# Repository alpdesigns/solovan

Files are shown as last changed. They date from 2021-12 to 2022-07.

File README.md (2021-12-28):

# Solovan
Solovan is a 15x3 ortholinear mechanical keyboard.

## Build Guides / ビルドガイド

- [Rev.A](./buildguide/rev_a)

## Firmware / ファームウェア

This keyboard uses the QMK firmware.

- https://github.com/alpdesigns/qmk_firmware
## PCB Data / 基板データ
### PCB Data License
- Licensed under a [Creative Commons Attribution-NonCommercial-ShareAlike 4.0 International License](http://creativecommons.org/licenses/by-nc-sa/4.0/) (CC BY-NC-SA 4.0) otherwise noted. 
- For footprints see https://github.com/kymok/kicad-libs.

### data

- [Rev.A](./pcb/rev_a) (MCU: ATMEGA32u4)

## Bottom Plate Data / 底面プレートデータ

### Bottom Plate Data License

(C) ALP Designs 2021 All Rights Reserved.
- The data are provided for convenience of making accessories such as jigs or fixtures.
- 治具や固定金物などのアクセサリ制作に便利なよう，穴位置の図面を公開しています．

### data

- [Rev.A](./drawings/)

## Discord

- https://discord.gg/nhzya4kw

## Acknowledgements / 謝辞

I am grateful to [しろし](https://twitter.com/shirofox) for discussing the spec and giving me useful feedbacks through prototyping phase. Also [オタヒーのサメ](https://twitter.com/otahinosame) for naming this keyboard. [QMK Firmware](https://qmk.fm), [KiCad](https://www.kicad.org), [REMAP](https://remap-keys.app) were the indispensable OSS projects that this keyboard relies on. I would like to thank [SMKiJ members](https://self-made-keyboards-in-japan.github.io) for generously sharing their experience and knowledge.

開発にあたり，[しろし](https://twiter.com/shirofox)さんに仕様の議論とプロトタイプの試用にご協力いただきました．[オタヒーのサメ](https://twitter.com/otahinosame)さんにはキーボードを命名していただきました．また，[QMK Firmware](https://qmk.fm), [KiCad](https://www.kicad.org), [REMAP](https://remap-keys.app) は欠くことのできない重要な OSS プロジェクトでした．経験と知識を日々共有してくださる [SMKiJ](https://self-made-keyboards-in-japan.github.io) の皆様には日々お世話になっています．この場を借りて感謝申し上げます．

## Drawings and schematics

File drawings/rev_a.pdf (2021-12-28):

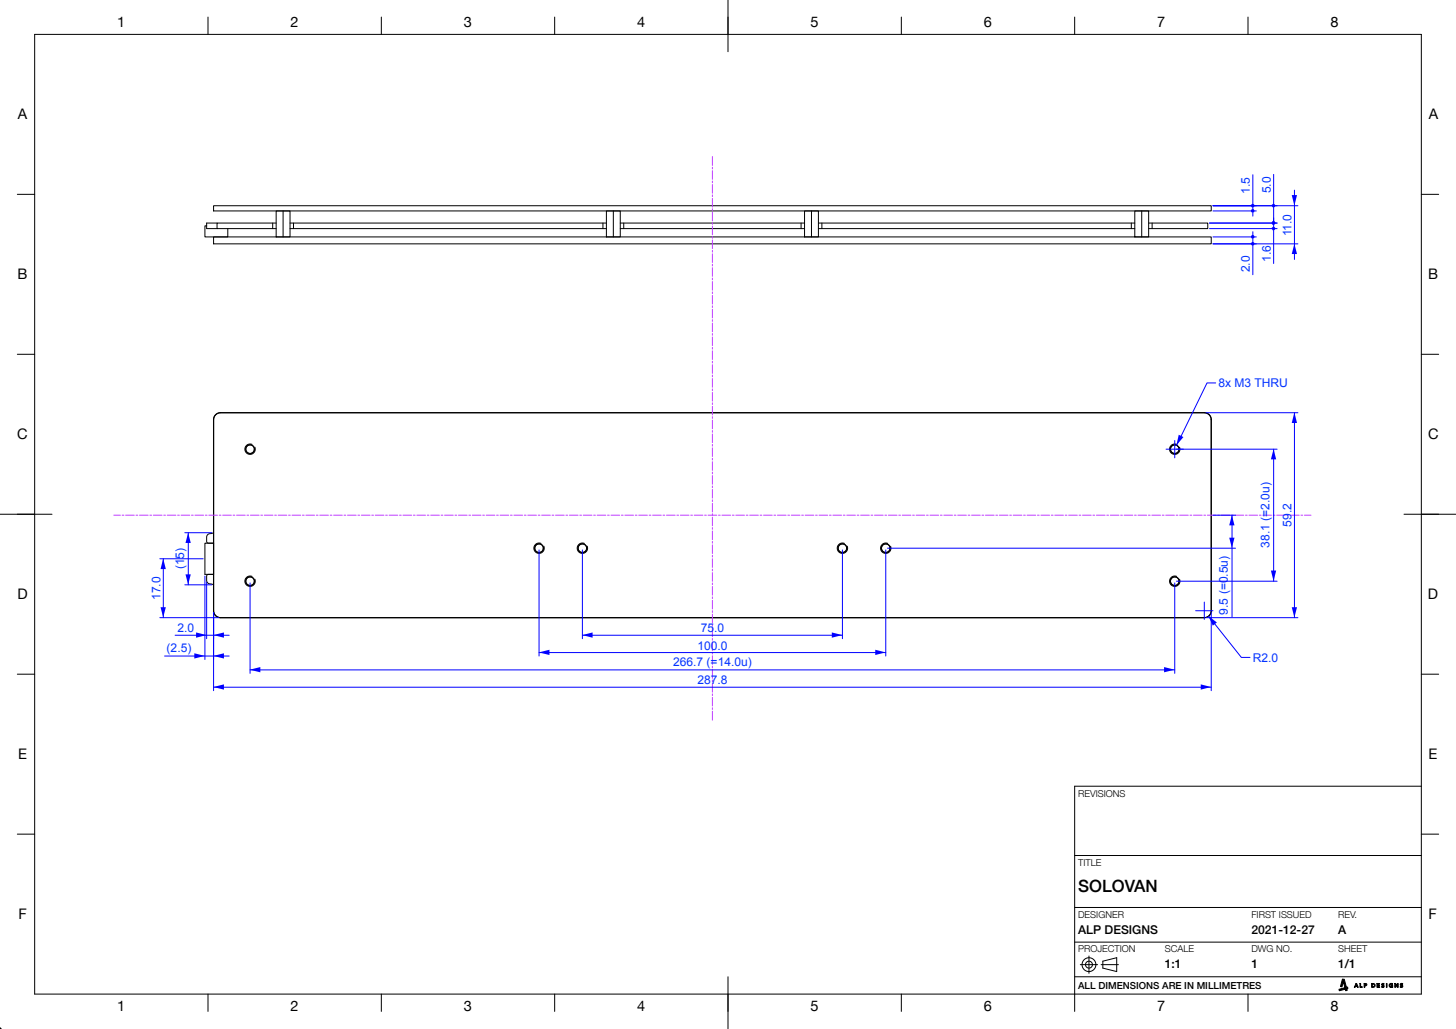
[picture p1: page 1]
8x M3 THRU; ALP DESIGNS; FIRST ISSUED; DWG NO.

ALL DIMENSIONS ARE IN MILLIMETRES

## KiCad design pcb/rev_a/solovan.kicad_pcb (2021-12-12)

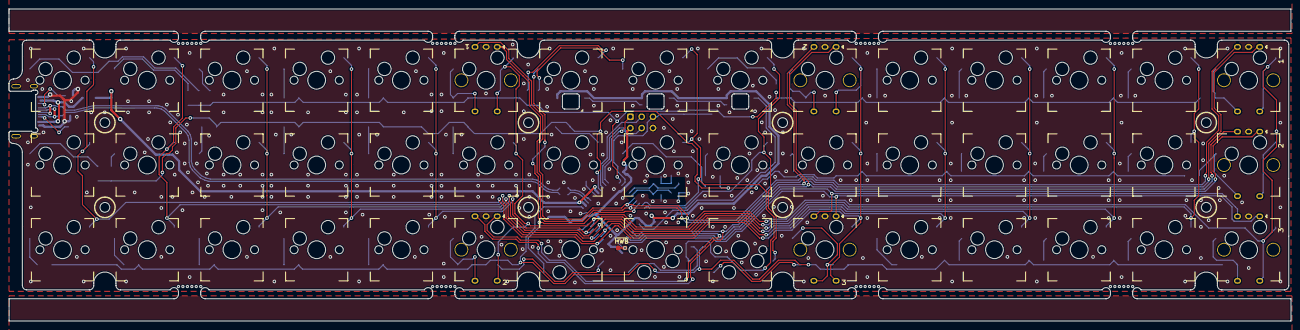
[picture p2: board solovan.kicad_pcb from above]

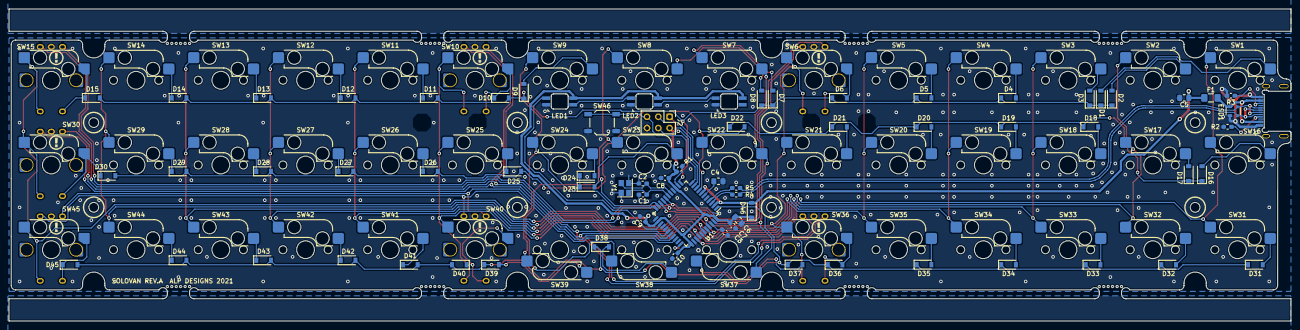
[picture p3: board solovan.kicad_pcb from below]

Board: 2 copper layers, 288.3 x 70.1 mm, 133 parts (71 on the bottom side), 85 nets.

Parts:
C1: 10p; C_0603_1608Metric_Pad1.08x0.95mm_HandSolder
C2: 10p; C_0603_1608Metric_Pad1.05x0.95mm_HandSolder
C3, C7, C8, C9, C10: 0.1u; C_0603_1608Metric_Pad1.05x0.95mm_HandSolder
C4, C5, C6: 1u; C_0805_2012Metric_Pad1.15x1.40mm_HandSolder
D1, D2, D3, D4, D5, D6, D7, D8, D9, D10, D11, D12, D13, D14, D15, D16, D17, D18, D19, D20, D21, D22, D23, D24, D25, D26, D27, D28, D29, D30, D31, D32, D33, D34, D35, D36, D37, D38, D39, D40, D41, D42, D43, D44, D45: 1N4148W; D_SOD-123
D46: 1N5819HW-7-F; D_SOD-123
ESD1: PRTR5V0U2X; SOT-143B
F1: 1206L050YR; Fuse_1206_3216Metric_Pad1.42x1.75mm_HandSolder
H1, H2, H3, H4, H5, H6, H7, H8: MountingHole; MountingHole_M2
H11, H12, H13, H14, H15, H16, H17, H18: MountingHole; Breakaway
J1: USB_C_Receptacle_USB2.0; HRO_TYPE_C_31_M_13
J2: ICSP; ICSP_ConnThrough
LED1, LED2, LED3: YS-SK6812MINI-E
NT1: Net-Tie_2; NetTie
R1: 10k; R_0603_1608Metric_Pad1.05x0.95mm_HandSolder
R2, R3: 5.1k; R_0603_1608Metric_Pad1.05x0.95mm_HandSolder
R4, R5: 22; R_0603_1608Metric_Pad1.05x0.95mm_HandSolder
SW1, SW2, SW3, SW4, SW5, SW7, SW8, SW9, SW11, SW12, SW13, SW14, SW16, SW17, SW18, SW19, SW20, SW21, SW22, SW23, SW24, SW25, SW26, SW27, SW28, SW29, SW31, SW32, SW33, SW34, SW35, SW37, SW38, SW39, SW41, SW42, SW43, SW44: Kailh MX Socket; SW_Cherry_MX_1.00u_Kailh
SW6, SW10, SW15, SW30, SW36, SW40, SW45: Rotary_Encoder_Switch_MP; SW_Cherry_MX_1.00u_Kailh_EC12
SW46: TS-1187A-B-A-B; SW_SPST_TL3342
U1: ATmega32U4-AU; TQFP-44_10x10mm_P0.8mm
Y1: X322516MLB4SI; Crystal_SMD_3225-4Pin_3.2x2.5mm

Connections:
/Col01: SW1.2, SW10.S1, SW16.2, SW25.2, SW31.2, SW40.S1, U1.36
/Col02: SW2.2, SW11.2, SW17.2, SW26.2, SW32.2, SW41.2, U1.37
/Col03: SW3.2, SW12.2, SW18.2, SW27.2, SW33.2, SW42.2, U1.38
/Col04: SW4.2, SW13.2, SW19.2, SW28.2, SW34.2, SW43.2, U1.39
/Col05: SW5.2, SW14.2, SW20.2, SW29.2, SW35.2, SW44.2, U1.40
/Col06: SW6.S1, SW15.S1, SW21.2, SW30.S1, SW36.S1, SW45.S1, U1.41
/Col07: SW7.1, SW22.1, SW37.2, U1.20
/Col08: SW8.2, SW23.2, SW38.1, U1.21
/Col09: SW9.2, SW24.2, SW39.1, U1.22
/D+: R5.1, U1.4
/D-: R4.1, U1.3
/MISO: J2.1, U1.11
/MOSI: J2.4, U1.10
/RE1A: SW6.A, SW15.A, U1.19
/RE1B: SW6.B, SW15.B, U1.18
/RE2A: SW10.A, SW30.A, SW36.A, U1.29
/RE2B: SW10.B, SW30.B, SW36.B, U1.28
/RE3A: SW40.A, SW45.A, U1.31
/RE3B: SW40.B, SW45.B, U1.30
/RGBLED: LED1.4, U1.25
/Row1: D1.1, D2.1, D3.1, D4.1, D5.1, D6.1, D7.1, D8.1, D9.1, D10.2, D11.2, D12.2, D13.2, D14.2, D15.2, U1.12
/Row2: D16.1, D17.1, D18.1, D19.1, D20.1, D21.1, D22.1, D23.1, D24.1, D25.2, D26.2, D27.2, D28.2, D29.2, D30.2, U1.8
/Row3: D31.1, D32.1, D33.1, D34.1, D35.1, D36.1, D37.1, D38.1, D39.1, D40.2, D41.2, D42.2, D43.2, D44.2, D45.2, U1.1
/SCK: J2.3, U1.9
/USBC_D1+: ESD1.3, J1.A6, J1.B6, R5.2
/USBC_D1-: ESD1.2, J1.A7, J1.B7, R4.2
/~RESET: J2.5, R1.2, SW46.1, U1.13
GND: C1.2, C2.2, C3.1, C4.1, C5.2, C6.2, C7.2, C8.2, C9.2, C10.2, ESD1.1, J1.A1, J1.A12, J1.B1, J1.B12, J1.S1, J2.6, LED1.3, LED2.3, LED3.3, NT1.2, R2.1, R3.1, SW6.C, SW10.C, SW15.C, SW30.C, SW36.C, SW40.C, SW45.C, SW46.2, U1.5, U1.15, U1.23, U1.35, U1.43, Y1.2, Y1.4
unnamed: C1.1, U1.17, Y1.1
unnamed: C2.1, U1.16, Y1.3
unnamed: C3.2, U1.42
unnamed: C4.2, U1.6
unnamed: D1.2, SW1.1
unnamed: D2.2, SW2.1
unnamed: D3.2, SW3.1
unnamed: D4.2, SW4.1
unnamed: D5.2, SW5.1
unnamed: D6.2, SW6.S2
unnamed: D7.2, SW7.2
unnamed: D8.2, SW8.1
unnamed: D9.2, SW9.1
unnamed: D10.1, SW10.S2
unnamed: D11.1, SW11.1
unnamed: D12.1, SW12.1
unnamed: D13.1, SW13.1
unnamed: D14.1, SW14.1
unnamed: D15.1, SW15.S2
unnamed: D16.2, SW16.1
unnamed: D17.2, SW17.1
unnamed: D18.2, SW18.1
unnamed: D19.2, SW19.1
unnamed: D20.2, SW20.1
unnamed: D21.2, SW21.1
unnamed: D22.2, SW22.2
unnamed: D23.2, SW23.1
unnamed: D24.2, SW24.1
unnamed: D25.1, SW25.1
unnamed: D26.1, SW26.1
unnamed: D27.1, SW27.1
unnamed: D28.1, SW28.1
unnamed: D29.1, SW29.1
unnamed: D30.1, SW30.S2
unnamed: D31.2, SW31.1
unnamed: D32.2, SW32.1
unnamed: D33.2, SW33.1
unnamed: D34.2, SW34.1
unnamed: D35.2, SW35.1
unnamed: D36.2, SW36.S2
unnamed: D37.2, SW37.1
unnamed: D38.2, SW38.2
unnamed: D39.2, SW39.2
unnamed: D40.1, SW40.S2
unnamed: D41.1, SW41.1
unnamed: D42.1, SW42.1
unnamed: D43.1, SW43.1
unnamed: D44.1, SW44.1
unnamed: D45.1, SW45.S2
unnamed: J1.A5, R2.2
unnamed: J1.B5, R3.2
unnamed: LED1.2, LED2.4
unnamed: LED2.2, LED3.4
unnamed: NT1.1, U1.33
UVCC-L: C5.1, D46.2, F1.1, U1.2, U1.7
VBUS-L: ESD1.4, F1.2, J1.A4, J1.A9, J1.B4, J1.B9
VCC-L: C6.1, C7.1, C8.1, C9.1, C10.1, D46.1, J2.2, LED1.1, LED2.1, LED3.1, R1.1, U1.14, U1.24, U1.34, U1.44

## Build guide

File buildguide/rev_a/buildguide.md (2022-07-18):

# Solovan Build Guide (Rev.A)

- `2022-01-05` Added instruction for back plate orientation

This build guide is translated from Japanese version. If there is any conflict, Japanese version should prevail.

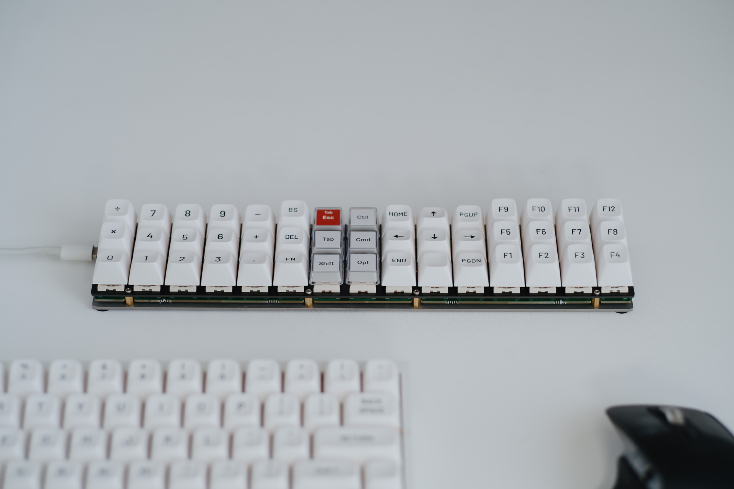
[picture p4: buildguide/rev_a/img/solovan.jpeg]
Solovan


Thank you for purchasing Solovan! 

Solovan is a 3x15 ortholinear keyboard. The board can be used as a depth saver or a adding some 40% to 60% keyboard. Also, it features 75 and 100 mm pitch M3 screw holes on the back side which is useful for attaching it to a display or a LCD tablet using commercially available hardwares (not included). Blasted stainless steel and dark grey anodised aluminum plate contributes its classy look and feel.

## Precautions

- This kit is for keyboard enthusiasts with proper knowledge of DIY keyboard.
- Some parts are fragile or may have sharp corners. Please handle with care.
- Sorry, but firmware development is not supported.

Products are carefully checked before shipment but please double-check for initial defects. If any problem, contact the seller within one week of receipt.

1. Check all parts are included in the box.
2. Check with [Remap](https://remap-keys.app) that all keys are working.

### About LEDs

Solovan has three LEDs which illuminates white when layer 1, 2 and 3 is active respectively. Modification to the firmware is required to change this behaviour. See [README](../../README.md) for the link to the firmware source code.

(LED flashes red when connected to USB.)

## Required Parts Not Included in the Kit

### Parts

|Item|Qty|
|:--|:--|
|Cherry MX key switch (or equivalent)|45|
|Cherry MX keycap 1u|45|
|Rotary encoder|3 max|
|Knob for rotary encoder|3 max|

Following rotary encoders can be used.

- ALPS EC12E2420801
- BOURNS PEC12R-4222F-S0024

### Equipments

|Item|Qty|
|:--|:--|
|USB Type-C data cable|1|
|Computer with Google Chrome (WebUSB must be enabled)|1|
|Tools|1 set|

Note: WebUSB may have been disabled in Google Chrome managed by your organization.

Following tools are recommended.

- Soldering iron and its holder
- Tweezers
- Side cutters
- Long-nose pliers or a M2 nut driver
- Screwdriver (+0)
- Solder and flux
- Solder wick
- Circuit tester with continuity check buzzer

## Inspection

### Parts in the Box

Following parts are included in this kit. Please check the quantity immediately after opening it.

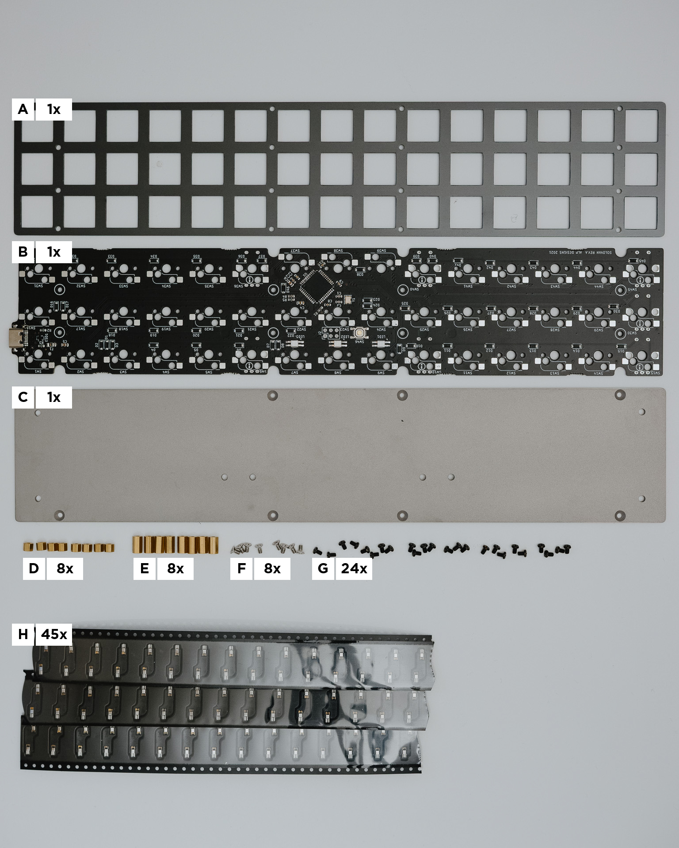
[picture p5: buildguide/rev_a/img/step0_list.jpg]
List of parts


|Symbol|Name|Qty|Rmks|
|:--|:--|:--|:--|
|A|Switch Plate|1||
|B|PCB|1||
|C|Bottom Plate|1||
|D|Standoff (M2x3.5 mm)|8|[Hirosugi ASB-2003.5CE](https://hirosugi.co.jp/products/B/ASB-CE.html) or equiv.|
|E|Standoff (M2x7.5 mm)|8|[Hirosugi ASB-2007.5CE](https://hirosugi.co.jp/products/B/ASB-CE.html) or equiv.|
|F|M2x4 stainless steel countersink screw|8|[Wilco UF-0204](https://wilco.jp/products/U/UF.html#page1) or equiv.|
|G|M2x3 black steel screw|24|[Wilco F-0230EB-03](https://wilco.jp/products/F/F-EB-03.html) or equiv.|
|H|Kailh MX socket|45||

### Inspecting the PCB

#### Inspecting Key Matrix

1. Access https://remap-keys.app with Google Chrome.
2. Connect Solovan.
3. Switch to key matrix testing mode.
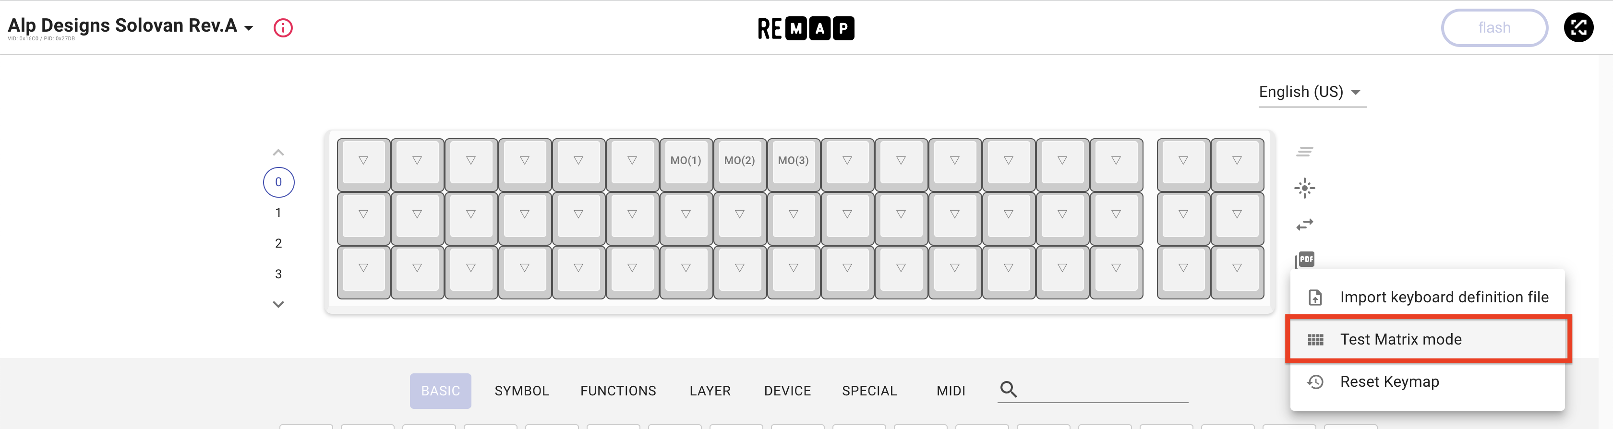
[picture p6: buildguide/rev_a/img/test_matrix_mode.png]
Testing mode
    - 
4. Short the pair of pads for each switches.
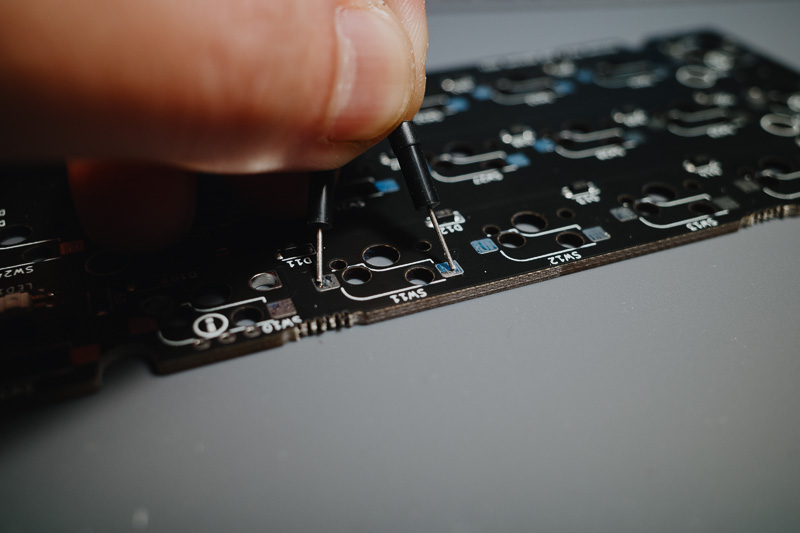
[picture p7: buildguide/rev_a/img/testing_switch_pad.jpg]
Shorting pads
    - 
5. Success if all switch except right cluster is highlighted. (The right cluster is for rotary encoders)
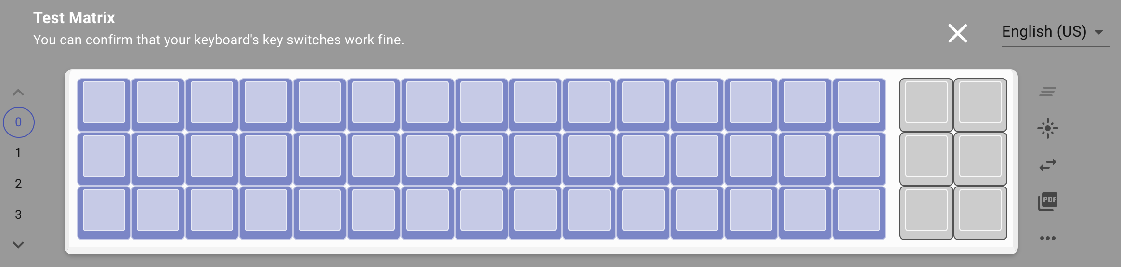
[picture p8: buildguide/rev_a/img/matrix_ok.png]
Success
    - 

#### Inspecting Rotary Encoder Circuit

1. Assign `MO(1)`, `MO(2)` for rotary encoder keys.
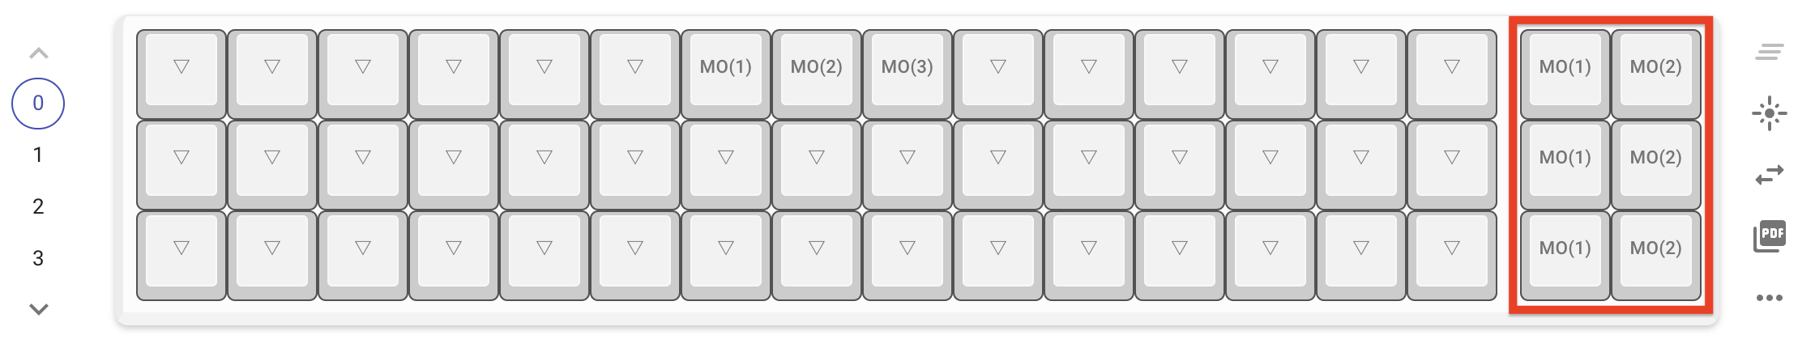
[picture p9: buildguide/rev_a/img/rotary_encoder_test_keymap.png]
rotary encoder inspection keymap
    - 
2. Half insert the rotary encoder and try turning the shaft to the left and right. Make sure that three pins touch the hole wall.
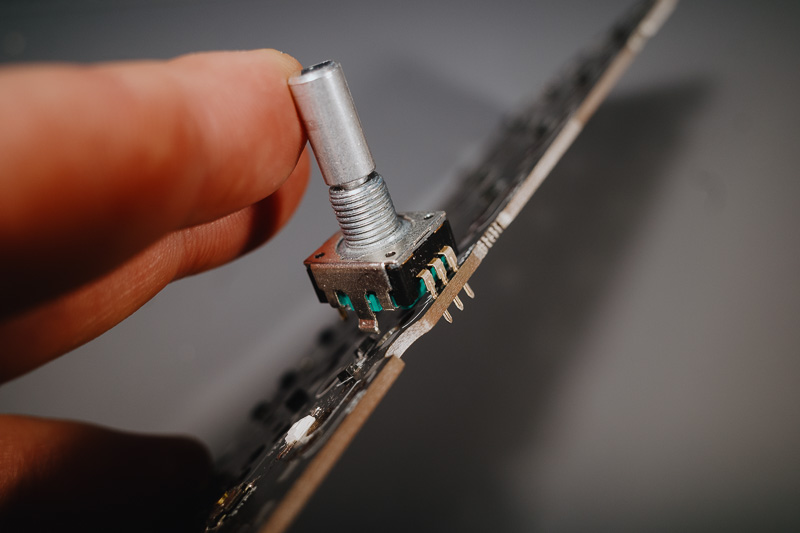
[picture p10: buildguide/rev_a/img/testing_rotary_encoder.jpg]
half inserting rotary encoder
    - 
3. Success if LED on the PCB flashes on rotating the encoder shaft.

## Assembling

### Choosing the place of rotary encoders

Rotary encoders can be placed on following footprints (Max 3). Footprint with the same number cannot be used at the same time. 

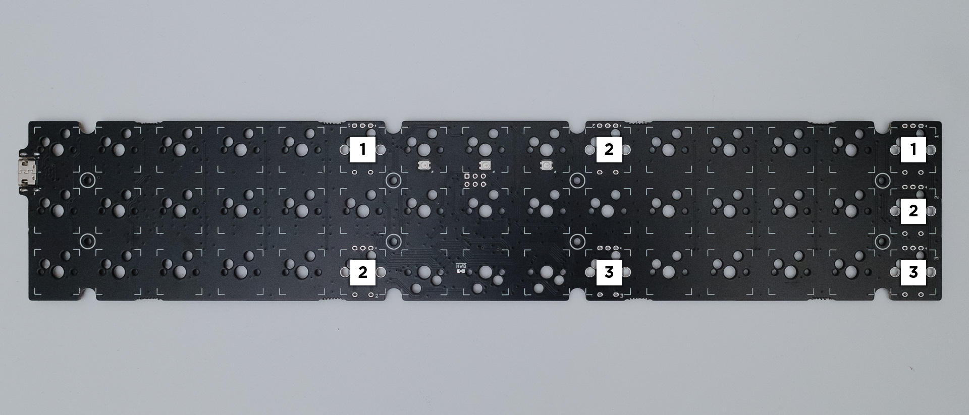
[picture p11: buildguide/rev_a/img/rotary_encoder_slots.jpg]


Rotary encoder functionality can be assigned using Remap.

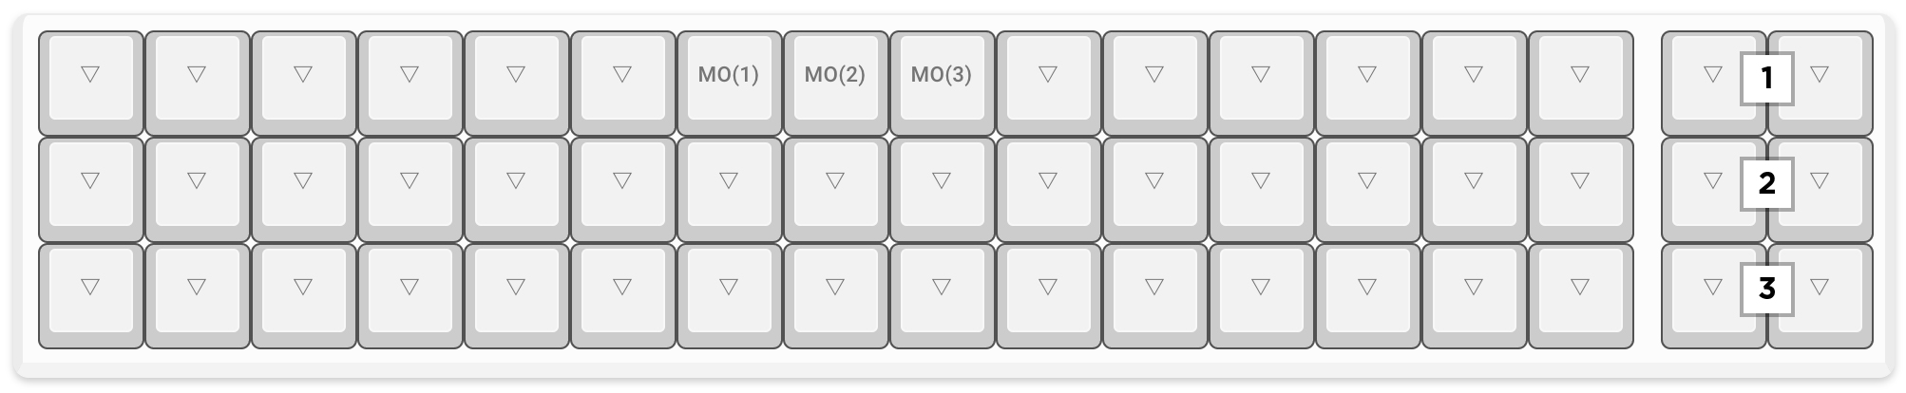
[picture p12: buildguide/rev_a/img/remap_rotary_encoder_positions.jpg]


### Assembling

1. Solder the Kailh socket.
    - **DO NOT solder to the footprints which are to be used with rotary encoders.**
    - Watch [Kailh socket soldering video](https://youtu.be/Mo56qdbEFzs) if needed.
    - Make sure not to solder sockets upside down.
2. Solder the rotary encoder.
    - Watch [rotary encoder soldering video](https://youtu.be/kJmX0Eaabzc) if needed.
    - If rotary encoders are too tight to plug them in, try bending their tab very slightly.
    - Trim the lead wires after soldering so that the remaining is ~2 mm. This is to prevent shortcircuit.
3. Attach standoffs to the switch plate.
    - **HANDLE WITH CARE: Aluminum plate is soft and prone to bend.**
    - Use standoffs `D` for inside holes and `E` for outside holes. Use screw `G`.
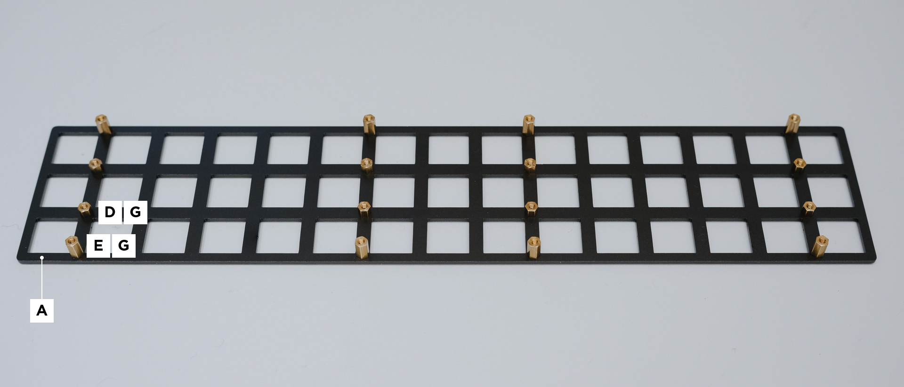
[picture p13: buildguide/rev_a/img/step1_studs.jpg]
    - 
4. Attach the PCB to the switch plate.
    - use screw `G`.
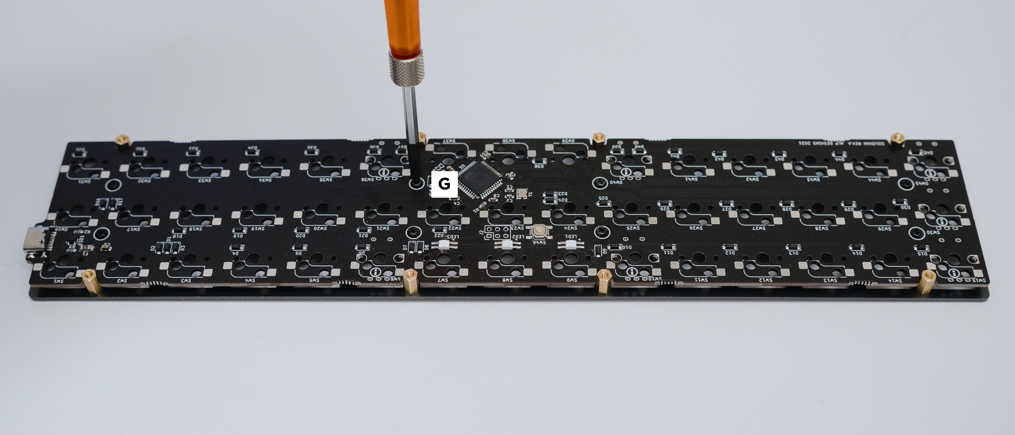
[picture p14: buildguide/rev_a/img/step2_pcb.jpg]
    - 
5. Attach the bottom plate.
    - use screw `F`.
    - `*1` Attach the plate so that the USB terminal and extra screw holes come to the same side. If the plate is attached in opposite direction, too long extra screws might damage the PCB.
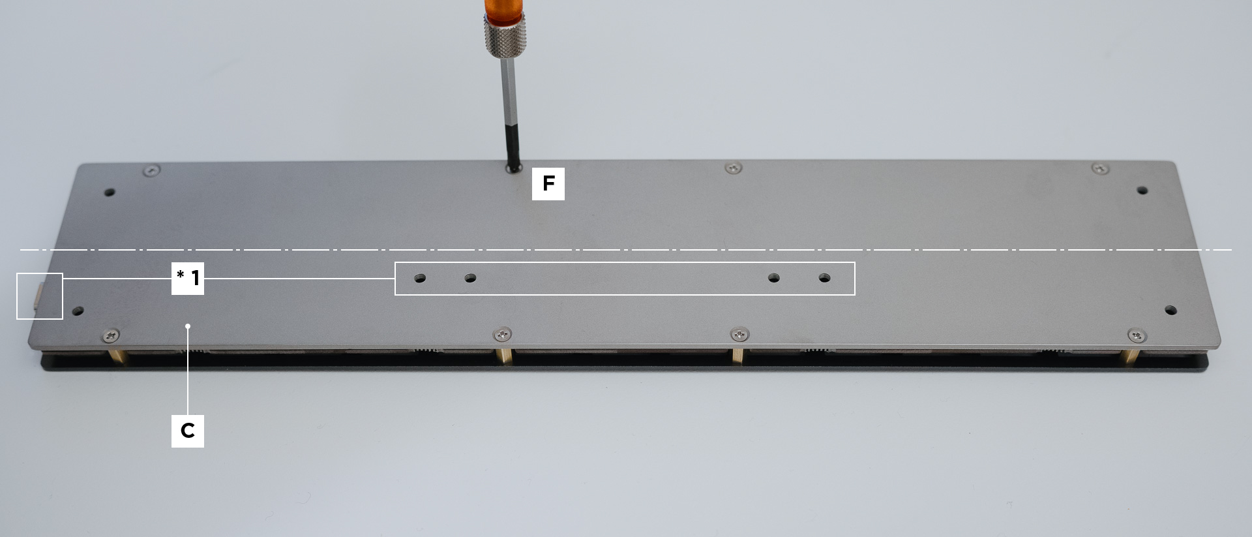
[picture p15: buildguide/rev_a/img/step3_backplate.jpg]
    - 
6. Attach rubber feets if needed.

## Setting Up Your Own Keymap

Navigating to https://remap-keys.app/ will let you edit your keymap.

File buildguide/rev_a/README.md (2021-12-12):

# Solovan Build Guide (Rev.A)

- [日本語](./buildguide_ja_JP.md)
- [English](./buildguide.md)

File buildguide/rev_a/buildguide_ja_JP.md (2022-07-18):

# Solovan ビルドガイド (Rev.A)

- `2022-01-05` 背面プレートの向きについての記述を追加

Solovan

ご購入ありがとうございます．

Solovan は，3行15列のオーソリニアキーボードです．単体で奥行の狭いキーボードとして利用するほか， 60% キーボードに足りないキーを補う使い方をするなど，さまざまな使い方が可能です．また，背面には 75 mm, 100 mm 間隔で M3 の穴がきってあり，ディスプレイの背面の穴と市販の金物を利用してディスプレイや液晶タブレット等に取り付けることもできます．

本体は，アルミ合金製のスイッチプレートとステンレスの背面プレートにより，サンドイッチ構造でありながら高級感のある見た目を特徴としています．

## 使用上の注意

- 本キットは，自作キーボードについての適切な知識のある方を対象としています．
- 製品には，一部鋭利なパーツや壊れやすいパーツがありますので，注意して扱ってください．
- まことに申し訳ありませんが，ファームウェア開発や，開発環境の構築はサポート外とさせていただきます．

検品は可能な限り行っておりますが，組立前に必ず以下の手順で初期不良のないことを確認してください（後述）．不具合が見つかった場合，お手数ですが商品到着後1週間以内に購入先へご連絡ください.

1. 部品が全て揃っていることを確認する.
2. Remapで全てのキーが認識されていることを確認する.

### LEDの動作について

上部3箇所にある LED は，左からレイヤ 1, 2, 3 が有効なときに白色に点灯します．この動作を変更するためにはファームウェアの書き換えが必要です．ファームウェアのソースコードへのリンクは [README](../../README.md) をご覧ください．

（接続時に一瞬だけ LED が赤色に点灯します）

## キット以外に必要なもの

### 部品

|品名|数量|
|:--|:--|
|Cherry MX キースイッチ 又は同等品|45個|
|Cherry MX 対応キーキャップ 1u|45個|
|ロータリーエンコーダ|最大3個|
|ロータリーエンコーダのつまみ|最大3個|

ロータリーエンコーダは，以下の型番で動作を確認しています．
- ALPS EC12E2420801
- BOURNS PEC12R-4222F-S0024

### 周辺機器・工具類

|品名|数量|
|:--|:--|
|データ通信可能な USB Type-C ケーブル|1本|
|WebUSB を有効にした Google Chrome が動作するコンピュータ|1台|
|工具|1式|

注意：組織で管理されたパソコンでは WebUSB が動作しないことがあります．

工具は以下のようなものがあると便利です．

- はんだごてとコテ台
- ピンセット
- ニッパー
- ラジオペンチ または ナットドライバー
- 精密ドライバー +0番
- はんだとフラックス
- はんだ吸い取り線
- テスター（導通時に音が鳴るもの）

## 動作確認

### 付属品の確認

本キットには，以下のものが含まれます．開封したらすぐに数量をご確認ください．

部品の一覧

|記号|品名|数量|備考|
|:--|:--|:--|:--|
|A|アルミプレート|1枚||
|B|基板|1枚||
|C|背面プレート|1枚||
|D|スペーサー (M2x3.5 mm)|8個|[廣杉計器 ASB-2003.5CE](https://hirosugi.co.jp/products/B/ASB-CE.html) 又は同等品|
|E|スペーサー (M2x7.5 mm)|8個|[廣杉計器 ASB-2007.5CE](https://hirosugi.co.jp/products/B/ASB-CE.html) 又は同等品|
|F|M2x4 皿小ねじ ステンレス|8個|[ウィルコ UF-0204](https://wilco.jp/products/U/UF.html#page1) 又は同等品|
|G|M2x3 精密機器用 0番3種 ＋なべ小ねじ 鉄三価クロメート黒染|24個|[ウィルコ F-0230EB-03](https://wilco.jp/products/F/F-EB-03.html) 又は同等品|
|H|Kailh MX ソケット|45個||

### 基板の動作確認

#### キーマトリクスの動作確認

1. Google Chrome で https://remap-keys.app にアクセスします．
2. Solovan を接続します．
3. キーマトリクスのテストを行うモードに切り替えます．
    - テストモード
4. スイッチのパッドを針金などでショートします．
    - パッドのショート
5. 以下のように全てのスイッチ部分に色がつけば成功です（右6つはロータリーエンコーダ用です）．
    - 確認後

#### ロータリーエンコーダを使う場合

1. ロータリーエンコーダ設定用のキー（右端6つ）に `MO(1)`, `MO(2)` を割り当てます．
    - ロータリーエンコーダの動作確認用
2. ロータリーエンコーダを半挿しにし，左右に回してみます．このとき，3本のピンが確実に穴の壁に触れるようにしてください．
    - ロータリーエンコーダを半挿しにする方法
3. ロータリーエンコーダを回すたびに基板の LED が一瞬点灯すれば成功です．

## 組立手順

### ロータリーエンコーダの場所を選ぶ

ロータリーエンコーダは，以下の場所に最大3つ取り付けることができます．ただし，同じ番号の場所には同時に取り付けることができません．



REMAP でロータリーエンコーダを回したときに送られるキーを設定できます．



### 組立て

1. Kailh ソケットをはんだづけします．
    - **ロータリーエンコーダを装着する予定の位置にはソケットを取り付けないでください．**
    - 必要に応じて[Kailh ソケットのはんだづけ動画](https://youtu.be/Mo56qdbEFzs)を参考にしてください．
    - 向きを間違えないよう注意してください．
2. ロータリーエンコーダをはんだづけします．
    - 必要に応じて[ロータリーエンコーダのはんだづけ動画](https://youtu.be/kJmX0Eaabzc)を参考にしてください．
    - ロータリーエンコーダが固くて入らない場合，爪を内側または外側にわずかに曲げると入ることがあります．
    - はんだづけ後，足を 2 mm 程度残してニッパーで切り落とします．これはショートを防止するためです．
3. スイッチプレートにスペーサーを取り付けます．
    - 内側に背の低いスペーサー `D` ，外側に背の高いスペーサー `E` を取り付けます．使用するねじは `G` です．
    - アルミプレートは柔らかく，曲がりやすいので注意して扱ってください．
    - 
4. スイッチプレートに基板を取り付けます．
    - 使用するねじは `G` です．
    - 
5. 背面プレートを取り付けます．
    - 使用するねじは `F` です．
    - `*1` USB端子と追加のねじ穴が中心に対して同じ側になるように取り付けてください．守らない場合，長すぎる追加のねじを使用すると，ねじの先端で基板の部品や配線を傷つけるおそれがあります．
    - 
6. 必要な場合，ゴム足を取り付けます．

## キーマップの設定

https://remap-keys.app/ にアクセスすると，キーマップの設定画面が表示されます．

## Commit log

2021-12-12 Add PCB data
    [solovan.kicad_pcb, solovan.sch]
2021-12-27 Add hole PDF data
2022-07-18 Add LED behaviour to the build guide
